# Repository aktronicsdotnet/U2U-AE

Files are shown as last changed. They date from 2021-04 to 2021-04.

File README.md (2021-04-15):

# U2U-AE
USB to UART Based on CH340G for Arduino and ESP
<br><br>
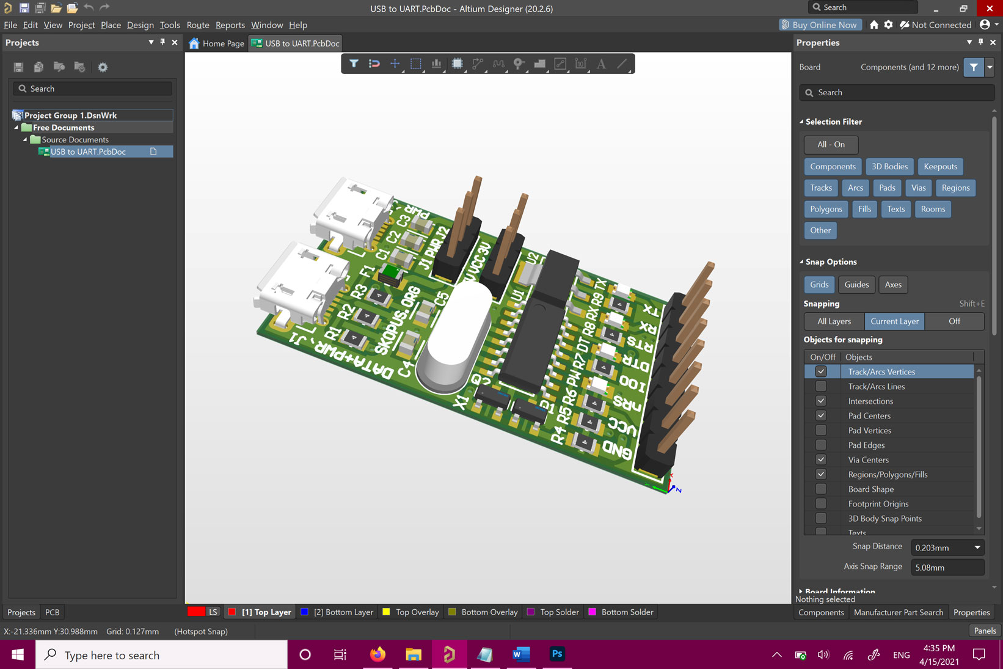
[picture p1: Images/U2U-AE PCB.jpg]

<br><br>
<b>
What is U2U-AE?
</b><br>
Well U2U-AE is a simple USB to UART converter that allow you to program AVR and ESP MCUs really easily, for AVR you just need GND, RX and TX lines... sometimes DTR too (for auto reset). For ESP8266 you also need nRST and GPIO0 to put ESP8266 into the correct mood at the right time. (google esp8266 bare minimum for more info about the simplest way you can run ESP8266)
<br><br>

<b>
What is different about U2U-AE?
</b><br>
Actually nothing is special about this board, with a little patience you can use any USB to UART board for serial communication but there are some advantages when you gather every feature on one single board...
<br>
-Uses cheap and readily available parts you can find in any country
<br>
-Small PCB with maximum uses of space (as much as possible)
<br>
-Fully documented and public knowledge
<br>
-Completely free of charge for any type of use
<br>
-Fully compatible with most AVR and ESP MCUs and many more devices probably
<br>
-Work with both 3.3V and 5V MCUs
<br>
-Power can be provided via a separate micro USB port to avoid damages to your PC
<br>
-Fused power line for more protection
<br>
-Separate LEDs for RX TX DTR and Power indication
<br>
-Can be easily adapted to USB-C connector or any other changes
<br><br>

<b>
Why is there two MICRO USB sockets?
</b><br>
It's just a precaution... personally I'm using a really expensive computer at the moment which is also a pain in the rear to repair it so I put two Micro USB sockets so that power and data can be separated from one another... Feel free to use 1 socket.
<br><br>

<b>
What are those jumpers for?
</b><br>
Well one set which USB port is responsible for providing power to the board and the other one will set the VCC voltage into 3.3V or 5V. Note that the voltage of every logic pin will change according to the VCC too, so make sure you use the proper voltage otherwise if it's too low your MCU might not like it and if it's too high it might burn your MCU...
<br><br>

<b>
In a nutshell:
</b><br>
Is it perfect? Probably not. Does it do flip overs? Of course not. Is it the best possible design? Far from it. But will it solve every need for a USB to UART? Most certainly will do!
<br><br>

<b>
How can I use this?
</b><br>
First you need to send the Gerber files from Gerber X2 folder to your fav PCB manufacturer and wait until they make the PCB for you and the you need to buy the necessary components according to the bill of material and when everything arrived careful solder them to the PCB and use it.
<br><br>

<b>
How hard is the soldering part?
</b><br>
Well I can tell you it's not for beginners... specially those Micro USB Ports are hard to solder by hands... (well not for me obviously!)
<br><br>

<b>
For more advanced users...
</b><br>
For more advanced users, I've left the original design so you can change anything you want. This board was designed by Altium Designer V20.
<br><br>

<b>
How can you find me?
</b><br>
I will leave my Instagram on this GitHub just in case you needed to contact me for any reason... Instagram @ skopusdotorg
<br><br>

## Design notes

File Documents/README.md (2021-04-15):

In this folder you will find the Schematic and the Bill of material as PDF and Microsoft Excel files...

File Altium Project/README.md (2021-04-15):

This folder is for more advanced users who would like to change anything in Schematic or PCB, the board was designed using Altium PCB Designer V20

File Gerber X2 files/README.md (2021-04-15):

Upload the "Gerber for USB to UART.zip" file to your fav PCB manufacturer...

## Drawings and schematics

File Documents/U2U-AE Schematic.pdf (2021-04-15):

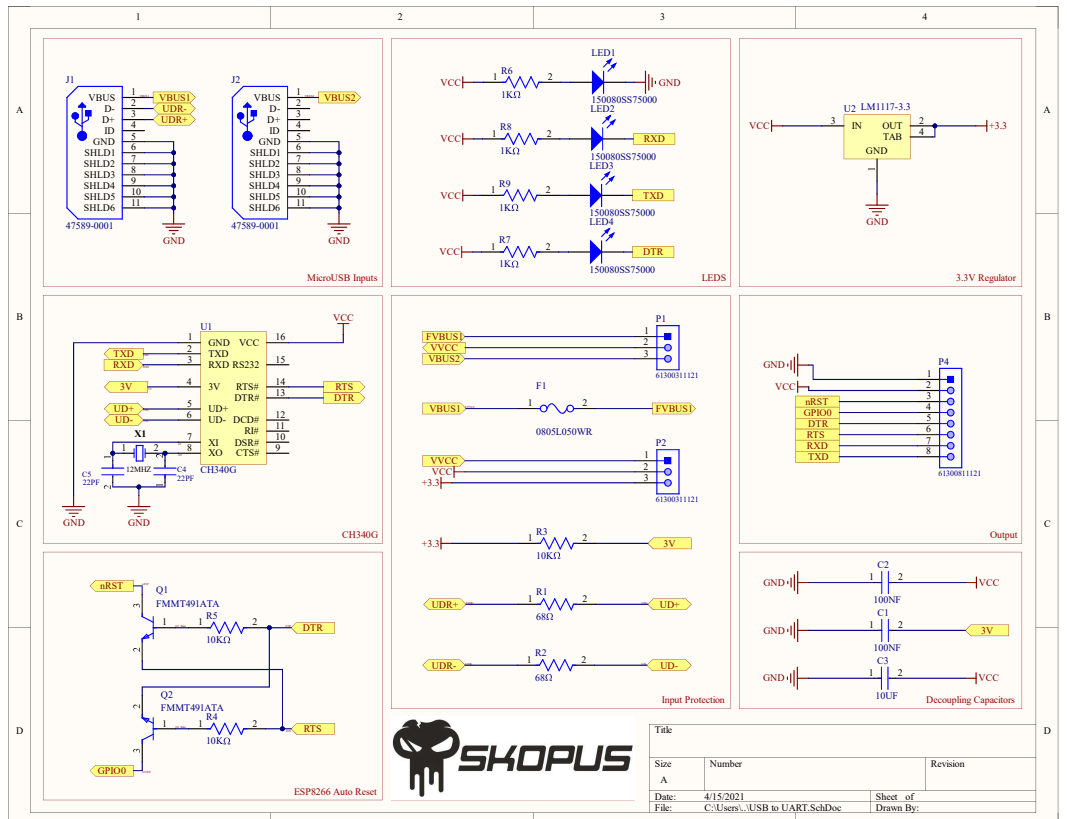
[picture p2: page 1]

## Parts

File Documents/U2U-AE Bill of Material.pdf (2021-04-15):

Altium Limited Confidential | 4/15/2021 | Page 1
Bill of Materials | Bill of Materials for Schematic Document [USB to UART.SchDoc]
Source Data From: | USB to UART.SchDoc
Project: | | Free Documents
Variant: | | None
Creation Date: 4/15/2021 | 1:52 PM
Print Date: | 15-Apr-21 | 1:52:28 PM
Footprint | Comment | LibRef | Designator | Description | Quantity
FP-C0805C-DN-MFG
| 100NF | CMP-2007-
00048-2
| | | C1, C2 | Capacitor; Ceramic; Cap; 22.0pF; Tol 5%;
SMT; Vol-Rtg 50V; C0G; Tape and Reel

2
FP-C0805C-DN-MFG
| 10UF | CMP-2007-
00048-2
| | | C3 | Capacitor; Ceramic; Cap; 22.0pF; Tol 5%;
SMT; Vol-Rtg 50V; C0G; Tape and Reel

1
FP-C0805C-DN-MFG
| 22PF | CMP-2007-
00048-2
| | | C4, C5 | Capacitor; Ceramic; Cap; 22.0pF; Tol 5%;
SMT; Vol-Rtg 50V; C0G; Tape and Reel

2
FP-0805L-MFG
| 0805L050WR | CMP-08606-
000023-1
F1 | PTC RESET FUSE 6V 500MA 0805 | 1
MOLX-47589-
0001_V
| 47589-0001 | CMP-2000-
05610-1
| | | J1, J2 | Right Angle Female Type AB Micro USB
Connector, 30 V, 1.8 A, -30 to 85 degC,

2
0805_A | 150080SS75000 | CMP-1426-
00010-1
| | | LED1, LED2, LED3, LED4 | SMD mono-color Chip LED, WL-SMCW,
Super Red

4
61300311121 | 61300311121 | CMP-1502-
01062-1
| | | P1, P2 | THT Vertical Pin Header WR-PHD, Pitch
2.54 mm, Single Row, 3 pins

2
61300811121 | 61300811121 | CMP-1502-
01076-1
| | | P4 | THT Vertical Pin Header WR-PHD, Pitch
2.54 mm, Single Row, 8 pins

1
FP-SOT23_Type
| FMMT491ATA | CMP-12798-
000029-1
| | | Q1, Q2 | TRANSISTOR NPN 40V 1A SOT23-3 -
ANY NPN TRANSOSTOR LIKE S8050

2
FP-CRCW0805-
| 68Ω | CMP-2001-
04940-2
| | | R1, R2 | RES Thick Film, 68Ω, 1%, 0.125W,
100ppm/°C, 0805

2
FP-CRCW0805-
| 10KΩ | CMP-2001-
04940-2
| | | R3, R4, R5 | RES Thick Film, 10KΩ, 1%, 0.125W,
100ppm/°C, 0805

3
FP-CRCW0805-
| 1KΩ | CMP-2001-
04940-2
| | | R6, R7, R8, R9 | RES Thick Film, 1kΩ, 1%, 0.125W,
100ppm/°C, 0805

4
D0016A_L | CH340G | CMP-1575-
00035-4
| | | U1 | High Speed CMOS 8-Channel Analog
Multiplexer/Demultiplexer, D0016A, TUBE

1
DCY0004A_L | LM1117-3.3 | CMP-0062-
01638-4
| | | U2 | 800mA Low-Dropout Linear Regulator, 4-
pin SOT-223, Pb-Free

1
FOX-FOXSLF-2_V
| 12MHZ | CMP-1749-
00004-1
| | | X1 | Resistance Weld Thru-Hole Crystal, 12
MHz, +/-30 ppm, -20 to 70 degC, 2-Pin

1
29
Approved | | Notes

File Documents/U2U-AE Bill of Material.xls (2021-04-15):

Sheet: BOM Report
Bill of Materials |  |  | Bill of Materials for Schematic Document [USB to UART.SchDoc]
Source Data From: |  | USB to UART.SchDoc
Project: |  | Free Documents
Variant: |  | None
Creation Date: | 4/15/2021 | 1:52 PM
Print Date: | 2021-04-15 | 13:52:20
Footprint | Comment | LibRef | Designator | Description | Quantity
FP-C0805C-DN-MFG | 100NF | CMP-2007-00048-2 | C1, C2 | Capacitor; Ceramic; Cap; 22.0pF; Tol 5%; SMT; Vol-Rtg 50V; C0G; Tape and Reel | 2
FP-C0805C-DN-MFG | 10UF | CMP-2007-00048-2 | C3 | Capacitor; Ceramic; Cap; 22.0pF; Tol 5%; SMT; Vol-Rtg 50V; C0G; Tape and Reel | 1
FP-C0805C-DN-MFG | 22PF | CMP-2007-00048-2 | C4, C5 | Capacitor; Ceramic; Cap; 22.0pF; Tol 5%; SMT; Vol-Rtg 50V; C0G; Tape and Reel | 2
FP-0805L-MFG | 0805L050WR | CMP-08606-000023-1 | F1 | PTC RESET FUSE 6V 500MA 0805 | 1
MOLX-47589-0001_V | 47589-0001 | CMP-2000-05610-1 | J1, J2 | Right Angle Female Type AB Micro USB Connector, 30 V, 1.8 A, -30 to 85 degC, RoHS, Tape and Reel | 2
0805_A | 150080SS75000 | CMP-1426-00010-1 | LED1, LED2, LED3, LED4 | SMD mono-color Chip LED, WL-SMCW, Super Red | 4
61300311121 | 61300311121 | CMP-1502-01062-1 | P1, P2 | THT Vertical Pin Header WR-PHD, Pitch 2.54 mm, Single Row, 3 pins | 2
61300811121 | 61300811121 | CMP-1502-01076-1 | P4 | THT Vertical Pin Header WR-PHD, Pitch 2.54 mm, Single Row, 8 pins | 1
FP-SOT23_Type_DN-MFG | FMMT491ATA | CMP-12798-000029-1 | Q1, Q2 | TRANSISTOR NPN 40V 1A SOT23-3 - ANY NPN TRANSOSTOR LIKE S8050 2N2222... | 2
FP-CRCW0805-e3-IPC_C | 68Ω | CMP-2001-04940-2 | R1, R2 | RES Thick Film, 68Ω, 1%, 0.125W, 100ppm/°C, 0805 | 2
FP-CRCW0805-e3-IPC_C | 10KΩ | CMP-2001-04940-2 | R3, R4, R5 | RES Thick Film, 10KΩ, 1%, 0.125W, 100ppm/°C, 0805 | 3
FP-CRCW0805-e3-IPC_C | 1KΩ | CMP-2001-04940-2 | R6, R7, R8, R9 | RES Thick Film, 1kΩ, 1%, 0.125W, 100ppm/°C, 0805 | 4
D0016A_L | CH340G | CMP-1575-00035-4 | U1 | High Speed CMOS 8-Channel Analog Multiplexer/Demultiplexer, D0016A, TUBE | 1
DCY0004A_L | LM1117-3.3 | CMP-0062-01638-4 | U2 | 800mA Low-Dropout Linear Regulator, 4-pin SOT-223, Pb-Free | 1
FOX-FOXSLF-2_V | 12MHZ | CMP-1749-00004-1 | X1 | Resistance Weld Thru-Hole Crystal, 12 MHz, +/-30 ppm, -20 to 70 degC, 2-Pin THD, RoHS, Bulk | 1
 |  |  |  |  | 29
Approved |  | Notes

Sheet: Project Information
Project Full Path | Free Documents
Project Filename | Free Documents
Variant Name | None
Data-Source Filename | USB to UART.SchDoc
Data-Source Full Path | C:\Users\khaza\Documents\Proteus\KaraPCB\Others\Unrelated Stuff\USB to UART\Altium Project\USB to UART.SchDoc
Title | Bill of Materials for Schematic Document [USB to UART.SchDoc]
Total Quantity | 29
Report Time | 1:52 PM
Report Date | 4/15/2021
Report Date & Tine | 4/15/2021 1:52 PM
Output Name | Bill of Materials
Output Type | BOM_PartType
Output Generator Name | BOM
Output Generator Description | Bill of Materials
